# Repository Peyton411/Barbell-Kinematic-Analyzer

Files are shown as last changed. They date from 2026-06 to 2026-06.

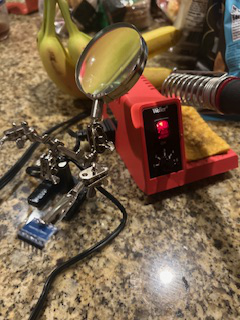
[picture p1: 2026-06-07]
Photo Gallery/Soldering_station.jpeg

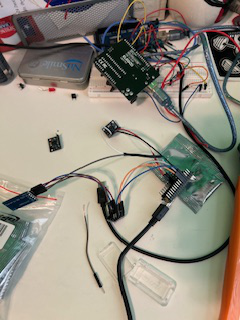
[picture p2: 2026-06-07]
Photo Gallery/Full_hardware_prototype.jpeg

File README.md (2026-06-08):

# Barbell Kinematics Analyzer



Description: A system to track barbell velocity through an IMU and approximate proximity to failure.

# Project planning
**1. Hardware Selection & Interfacing:** Select, solder, and wire the components
**2. Raw Sensor Evaluation:** Get raw IMU readings running
**3. Live Telemetry Streaming:** Log wireless data packages through the BLE into csv files
**4. Rep Detection & Metric Tracking:** Breaking the reps into concentric and eccentric to count reps, get useful metrics like average velocity
**5. Physical Mounting:** Model and 3D print a way to mount the system onto the barbel
**6. Estimate proximity to failure:** Predict failure points using a simple ML model

## Hardware Architecture & Physical Wiring

**Components and usages:**

**Arduino Nano:** microcontroller

**MPU6050:** accelerometer and gyroscope

**HM-10 BLE Module:** wireless capacities

**Logic level convertor:** makes BLE work with Nano

**Power supply:** Ekrist 25800mAh Battery Portable Charger 

Because the BLE takes 3.3V and the arduino sends 5V, a logic level converter had to be integrated, which controlled the voltage to save the BLE.

## Wiring

MPU6050:

**VCC - Nano 5V

GND - NANO GND

SDA - NANO A4

SCL - Nano A5

BLE HM-10 RX:

VCC - Nano 3.3V  

GND - GND Nano

TXD - LLC LV2

RXD - LLC LV1

Logic level convertor:

HV:

HV1 - Nano D2

HV2 - Nano D3

LV:

LV1 - HM-10 RX

LV2 - HM-10 TX

Note on wiring- During the physical fabrication stage, the GND and VCC pins were scarce, so I made Y-splices to distribute power to the MPU6050, HM-10 BLE, and Logic Level Converter.

Y-Splice

**Y-splice creation**

Full_hardware_prototype

**Full hardware protype**

## Software and Engineering Development Logs

### 1. Getting Started Up
**Problem** Whenever I started up a prototype of just the IMU and Nano, the IMU would glitch because the Nano and IMU started up at different times.

**Fail** The first MPU6050 was fried while soldering pins on. The ruined board was used to practice soldering.

Soldering_station

**Soldering IMU pins**

**Fix** Wrote code to check if there was a connection to the IMU at address `0x68`. To prevent it from getting stuck booting up, code turning the SCL clock up and down 9 times was implement to wake the IMU back up.



**Raw IMU data collection**

### 2. Sensor Fusion
* **The Problem:** Sensor noise and tilting the IMU caused infinite velocity drift because the orientation was not taken into account.
* **The Fix:** Added a Complementary Filter combining gyroscope angles with accelerometer readings to track tilt and orientation angles. Began subtracting gravity vectors to get true velocity. A  deadband limit paired with ae stillness check zeroes out tilt when the sensor rests between reps.

## BLE Connection and Data Logging

### 1. BLE Communication Debugging

* **The Problem:** Although the HM-10 was pairing successfully, no sensor data was being received by the laptop.
* **The Fix:** Traced the issue to an incorrect TX/RX wiring configuration between the Arduino Nano and HM-10 BLE module. After rewiring the connections, the communication was restored.
* **The Result:** The BLE module was able to reliably transmit sensor data from the Arduino to the laptop.

### 2. Wireless Data Logging

* **The Problem:** The project required a way to collect sensor data wirelessly and store it in a format suitable for later analysis.
* **The Fix:** Modified a Python logging script to receive BLE packets and save them directly into CSV files (https://github.com/tarik-ibrahimovic/hweeai_IDK/blob/835bf81b631bc8ac133e5d8dc36f2bbcbaa82166/bt_csv.py#L24). A simple handshake protocol was implemented, requiring commands from the laptop before calibration and data collection could begin. Timestamps were transmitted alongside velocity measurements.
* **The Result:** Timestamped sensor data could be streamed wirelessly and be written into csv files.

  *CSV writing terminal, connection

  **CSV writing script in action**

### 3. Packet Structure & Reliability

* **The Problem:** BLE transmissions can arrive in incomplete chunks, creating the possibility of corrupted or misaligned data packets.
* **The Fix:** Instead of implementing a start-byte synchronization system, a software buffer was added on the Python side to wait until a complete packet had been received before processing it. Existing BLE logging software was adapted by modifying the Arduino packet format to match the expected structure.
* **The Result:** Reliable packet reception was achieved without requiring additional packet framing logic.

Collected CSV file when Still

**CSV file when IMU is still**

### 4. Data Processing Automation

* **The Problem:** To maintain compatibility with the logging software, several unused placeholder values were included in transmitted packets, resulting in unnecessary columns in exported CSV files.
* **The Fix:** Wrote a secondary Python utility to automatically remove unused columns and generate cleaner datasets.
* **The Result:** Data could be exported into a simplified format better suited for analysis and future machine learning applications.

CSV file organizing
Refined CSV file

**CSV file refinement**

## CAD Modeling the Battery Case and Electronics box (Opted to use commercial barbell clips and attach the separate components)

Designed a model to keep the  Ekrist 25800mAh battery pack (3"L x 4.7"W x 1"Th) in place and safe during lifts through Fusion360.

The design changed across three revisions to abide by physical constraints:
1. **Revision 1 (A box):** A basic rectangular shell with 0.1 inches of clearance in all directions, opening for charging and powering, tailored to the dimensions of the battery, and space given to make sure battery doesn't overheat.

Battery_case_Revision_1
   
2. **Revision 2 (Heat and Strength management):** Thickened the base to 0.25 inches to handle barbell drops. Added fillets to help absorb impact and left at least 30% of the battery surface area exposed to prevent thermal overheating, as recommended. And added access to the power button and USB ports.

Battery_case_revision_2

3. **Revision 3 (Slicing):** To avoid steep overhang failures and messy prints, the casing was modified with a U shaped cut instead of a gaping hole, allowing it to print easier.

Battery_case_final

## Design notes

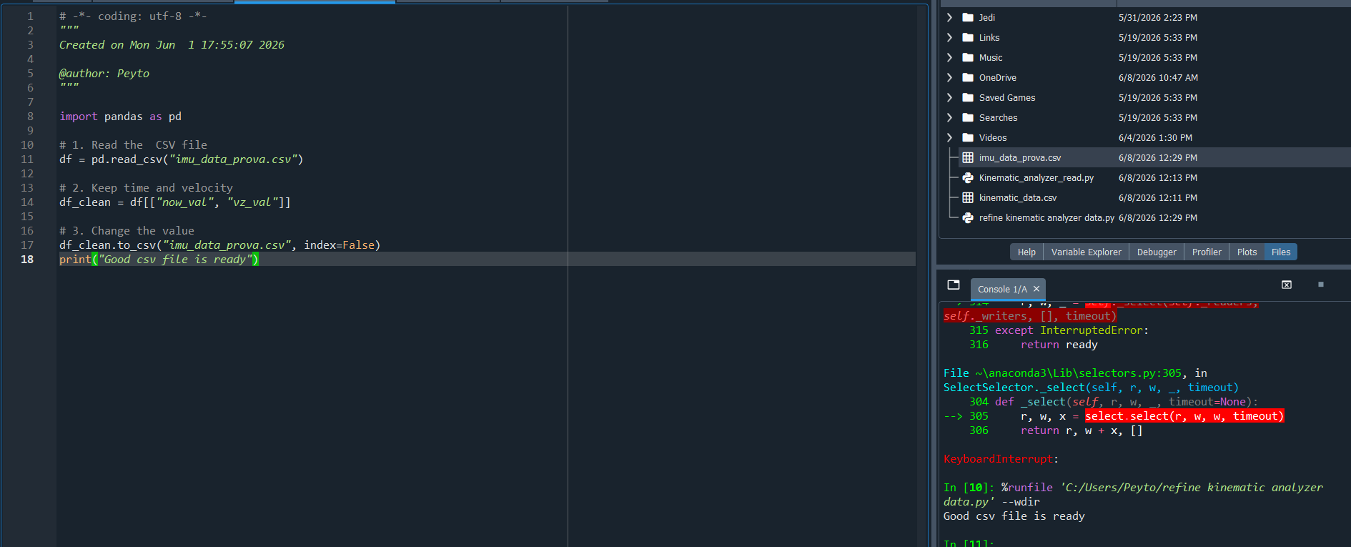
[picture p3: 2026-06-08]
Photo Gallery/CSV file organizing.png

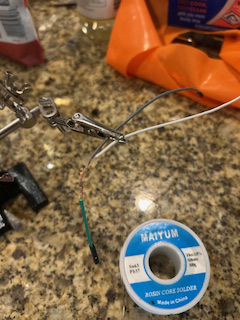
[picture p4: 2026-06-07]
Photo Gallery/Y-Splice.jpeg

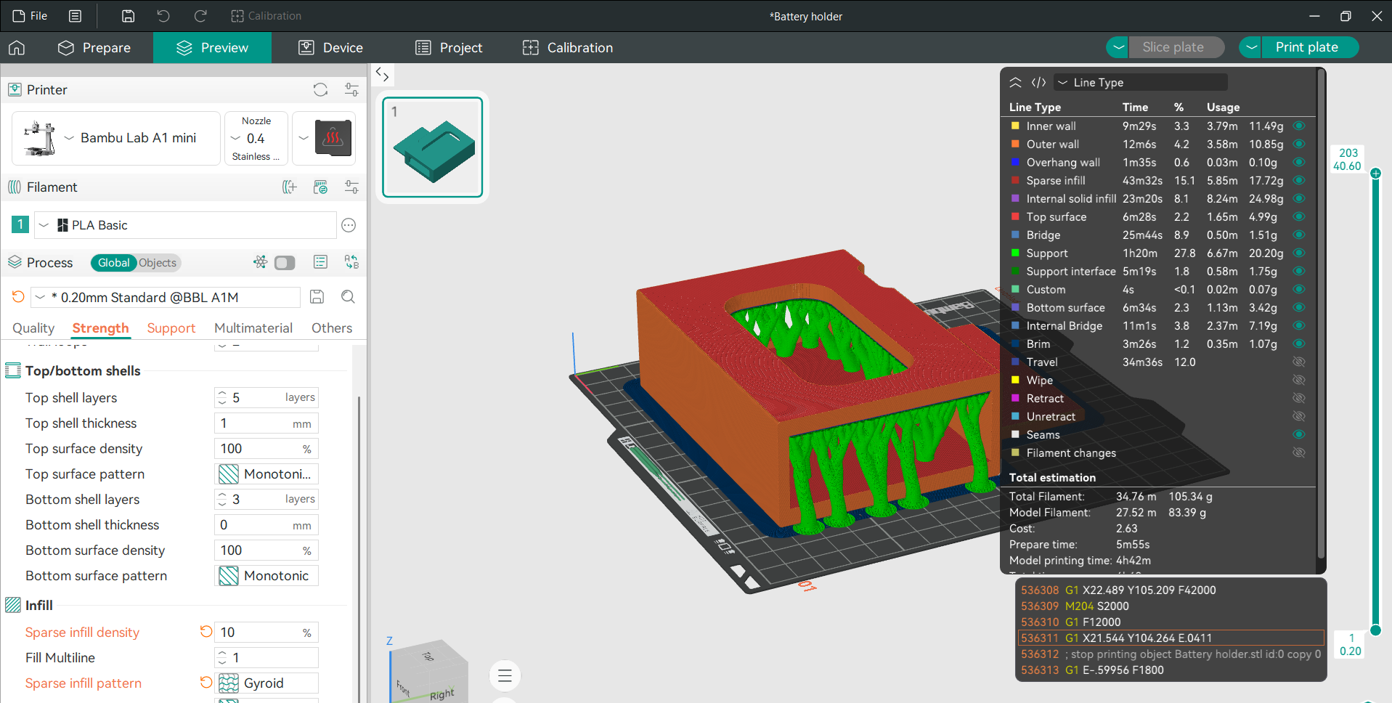
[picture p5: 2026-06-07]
Photo Gallery/Battery_case_slicing.png

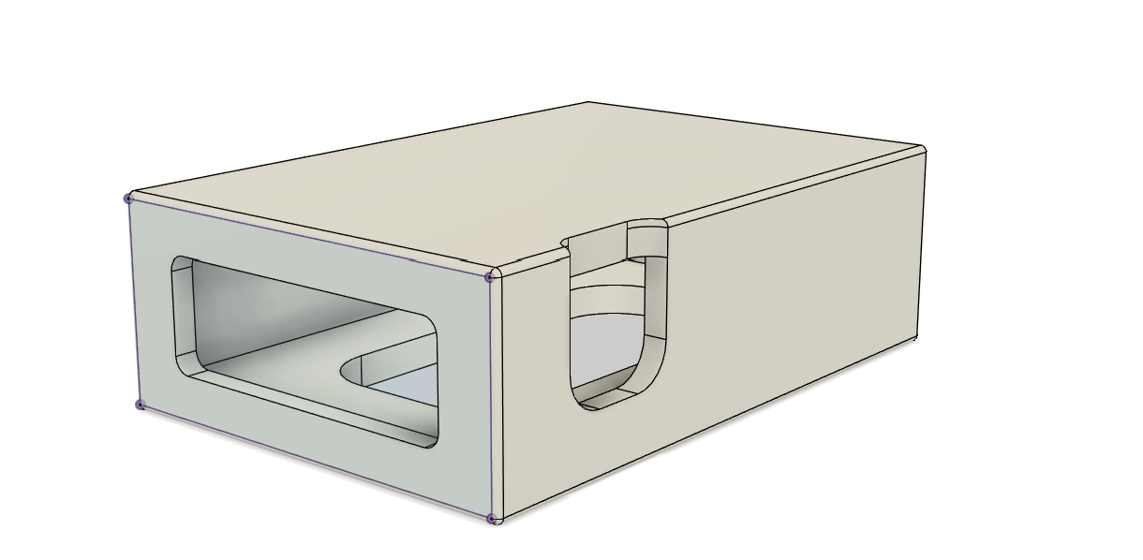
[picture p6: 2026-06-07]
Photo Gallery/Battery_case_3rd.png

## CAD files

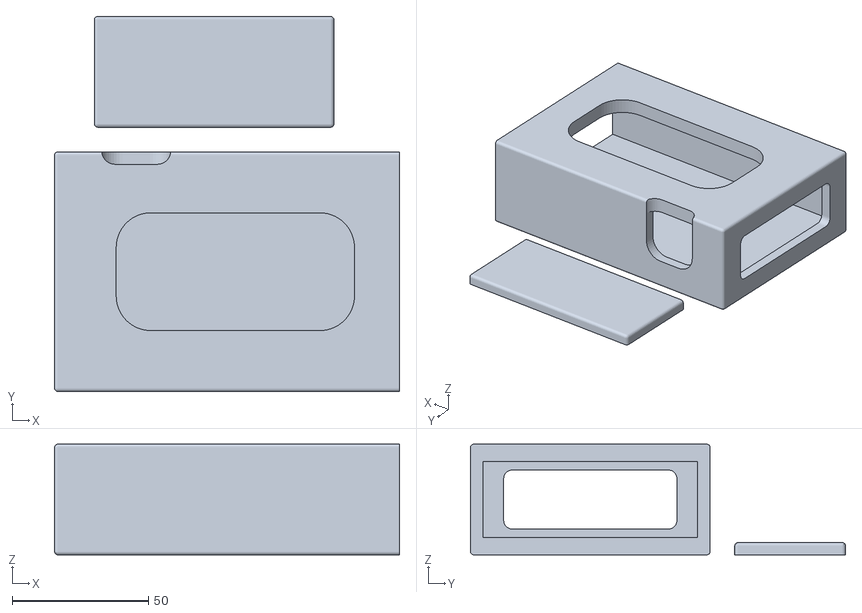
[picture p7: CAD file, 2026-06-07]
Hardware/3D Prints/Battery holder.stl
126.5 x 137.5 x 40.6

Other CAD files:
Hardware/3D Prints/Battery holder_PLA_4h48m.gcode.3mf

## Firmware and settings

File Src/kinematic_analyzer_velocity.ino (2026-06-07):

#include <Wire.h>
#include <math.h>
#include <SoftwareSerial.h>
#define MPU 0x68
union DataPacket {
  struct {
    float now_val;
    float vz_val;
    float fake1;
    float fake2;
    float fake3;
    float fake4;
  } values;
  byte bytes[24];
};
SoftwareSerial bleSerial(2,3);
float gx_offset = 0, gy_offset = 0, gz_offset = 0;
float ax_offset = 0, ay_offset = 0, az_offset = 0;
float vz = 0;
float anglex = 0, angley = 0;
unsigned long lastTime = 0;
unsigned long lastBleSend = 0; 
const unsigned long bleInterval = 50; //time between transmission
bool liftStart = false; // Is the lift started?
bool connection = false; //is the BLE connected?

void calibrate() {
  Serial.println("Calibrating - keep still...");
  long sumGX = 0, sumGY = 0, sumGZ = 0;
  long sumAX = 0, sumAY = 0, sumAZ = 0;
  int samples = 1000;

  for (int i = 0; i < samples; i++) {
    Wire.beginTransmission(MPU);
    Wire.write(0x3B);
    Wire.endTransmission(false);
    Wire.requestFrom(MPU, 14, true);

    sumAX += (int16_t)(Wire.read() << 8 | Wire.read());
    sumAY += (int16_t)(Wire.read() << 8 | Wire.read());
    sumAZ += (int16_t)(Wire.read() << 8 | Wire.read());
    Wire.read(); Wire.read(); // skip temp
    sumGX += (int16_t)(Wire.read() << 8 | Wire.read());
    sumGY += (int16_t)(Wire.read() << 8 | Wire.read());
    sumGZ += (int16_t)(Wire.read() << 8 | Wire.read());
    delay(3);
  }

  ax_offset = (sumAX / samples) / 16384.0;
  ay_offset = (sumAY / samples) / 16384.0;
  az_offset = (sumAZ / samples) / 16384.0 - 1.0; // bias only tje gravity is handled separately
  gx_offset = (sumGX / samples) / 131.0;
  gy_offset = (sumGY / samples) / 131.0;
  gz_offset = (sumGZ / samples) / 131.0;

  Serial.println("Done.");
}

void setup() {
  pinMode(A4, OUTPUT);
  pinMode(A5, OUTPUT);
  for (int i = 0; i < 9; i++) {
    digitalWrite(A5, HIGH);
    delayMicroseconds(5);
    digitalWrite(A5, LOW);
    delayMicroseconds(5);
  }
  digitalWrite(A4, HIGH);
  digitalWrite(A5, HIGH);
  pinMode(A4, INPUT);
  pinMode(A5, INPUT);

  Wire.begin();
  Serial.begin(9600);
  bleSerial.begin(9600);

  Wire.beginTransmission(MPU);
  Wire.write(0x6B);
  Wire.write(0);
  Wire.endTransmission(true);

  delay(100);
  Serial.println("Waiting for connection...");
  while (!connection) {
    if (bleSerial.available() > 0) {
      char incomingsignal = bleSerial.read();
      if (incomingsignal == 'C') { // 'C' for connected to my laptop
        connection = true;
      }
    }
    delay(10);
  }
  Serial.println("Connection established");
  while (!liftStart) {
    if (bleSerial.available() > 0) {
      char incomingsignal2 = bleSerial.read();
      if (incomingsignal2 == 'S') { // 'S' for starting the lift
        liftStart = true;
      }
    }
    delay(10);
  }
  calibrate();
  lastTime = millis();
}

void loop() {
  Wire.beginTransmission(MPU);
  Wire.write(0x3B);
  Wire.endTransmission(false);
  Wire.requestFrom(MPU, 14, true);

  int16_t ax = Wire.read() << 8 | Wire.read();
  int16_t ay = Wire.read() << 8 | Wire.read();
  int16_t az = Wire.read() << 8 | Wire.read();
  int16_t tmp = Wire.read() << 8 | Wire.read();
  int16_t gx = Wire.read() << 8 | Wire.read();
  int16_t gy = Wire.read() << 8 | Wire.read();
  int16_t gz = Wire.read() << 8 | Wire.read();

  unsigned long now = millis();
  float dt = (now - lastTime) / 1000.0;
  lastTime = now;

  // calibrated values - az_offset has bias only, so az_real  ks always around 1.0g at rest flat
  float ax_real = (ax / 16384.0) - ax_offset;
  float ay_real = (ay / 16384.0) - ay_offset;
  float az_real = (az / 16384.0) - az_offset;
  float gx_deg = (gx / 131.0) - gx_offset;
  float gy_deg = (gy / 131.0) - gy_offset;

  // checks for stillness
  // regardless of orientation, It will change when the bar accelerates
  float totalAccel = sqrt(ax_real*ax_real + ay_real*ay_real + az_real*az_real);
  bool isStill = (abs(totalAccel - 1.0) < 0.07);

  // only update tilt estimate when still - during movement accel is screwed up
  // by linear acceleration and gives wrong angles
  if (isStill) { 
    float accelAngleX = atan2(ay_real, az_real) * 180.0 / PI;
    float accelAngleY = atan2(ax_real, az_real) * 180.0 / PI;
    anglex = 0.98 * (anglex + gx_deg * dt) + 0.02 * accelAngleX;
    angley = 0.98 * (angley + gy_deg * dt) + 0.02 * accelAngleY;
  }

  // gravity vector from current tilt estimate (trig)
  float gravityZ = cos(anglex * PI / 180.0) * cos(angley * PI / 180.0);

  // subtract gravity to get real linear acceleration, convert to m/s^2
  float linear_az = (az_real - gravityZ) * 9.81;

  // small deadband for noise
  if (abs(linear_az) < 0.02) linear_az = 0;

  // adding
  vz += linear_az * dt;

  // bleed when still, which means just letting the velocity decrease
  if (isStill) {
    vz *= 0.9;
  }

  // reset near zero
  if (abs(vz) < 0.02) vz = 0;
static unsigned long stillStart = 0;
bool nearStill = (abs(vz) < 0.05) && (abs(totalAccel - 1.0) < 0.03);

if (nearStill) {
  if (stillStart == 0) stillStart = millis();

  if (millis() - stillStart > 200) {
    vz = 0;
  }
} else {
  stillStart = 0;
}
DataPacket packet;
packet.values.now_val = (float)now; // Turns unsigned long time into a float
packet.values.vz_val  = vz;   // Velocity
packet.values.fake1  = 0.0;    // Fills the fakes with zero
packet.values.fake2  = 0.0;
packet.values.fake3  = 0.0;
packet.values.fake4  = 0.0;

// Write out 24 bytes
bleSerial.write(packet.bytes, 24);
  delay(50);
}

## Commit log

2026-06-07 Rename Screenshot 2026-06-06 171925.png to Battery_Case_1st.png
2026-06-07 Rename Screenshot 2026-06-06 172855.png to Battery_case_2.png
2026-06-07 Rename Screenshot 2026-06-06 173323.png to Battery_case_3rd.png
2026-06-07 Rename Screenshot 2026-06-06 175022.png to Battery_case_final.png
2026-06-07 Rename Screenshot 2026-06-06 194505.png to Battery_case_slicing.png
